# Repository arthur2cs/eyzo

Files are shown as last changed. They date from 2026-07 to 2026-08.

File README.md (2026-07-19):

# eyzo

Eyzo - contrôle des lunettes connectées ESP32

## Getting Started

This project is a starting point for a Flutter application.

A few resources to get you started if this is your first Flutter project:

- [Lab: Write your first Flutter app](https://docs.flutter.dev/get-started/codelab)
- [Cookbook: Useful Flutter samples](https://docs.flutter.dev/cookbook)

For help getting started with Flutter development, view the
[online documentation](https://docs.flutter.dev/), which offers tutorials,
samples, guidance on mobile development, and a full API reference.

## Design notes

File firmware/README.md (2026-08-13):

# Firmware ESP32 — Lunettes Eyzo

Firmware pour le **Seeed Studio XIAO ESP32S3**, pilotant les 2 écrans SPI
ST7735S 1,77" et le bouton poussoir des lunettes, et implémentant le
protocole BLE défini dans `specs.md` (§6) à la racine du projet.

Le code source est dans le dossier [`EyzoFirmware/`](./EyzoFirmware) — c'est
ce dossier qu'il faut ouvrir dans Arduino IDE (double-clic sur
`EyzoFirmware.ino`).

> Ce firmware a été **compilé avec succès** (`arduino-cli compile`, core
> `esp32:esp32` v3.3.11, carte `XIAO_ESP32S3`, PSRAM=OPI) — 17 % flash / 12 %
> RAM utilisés (dernière vérification). Le socle (écrans, bouton, connexion
> BLE, envoi de texte/images/animations compressés en zlib via
> `SET_ANIMATION`) **a été validé sur le matériel réel** — **important :
> nécessite l'option `PSRAM=OPI` activée dans Arduino IDE**
> (`Outils > PSRAM > OPI PSRAM`), sans quoi le buffer de réassemblage BLE ne
> s'alloue pas et toute commande échoue silencieusement (voir §5 sur
> l'ACK/NACK applicatif, désormais consommé côté app). Les nouvelles
> cadences de défilement/clignotement (`stepIntervalFromSpeed()` /
> `blinkHalfPeriodFromSpeed()`, voir §4) sont en revanche **encore
> seulement validées à la compilation**, pas encore testées sur le matériel
> réel.

## 1. Installation Arduino IDE

### 1.1 Support de carte ESP32

1. **Fichier > Préférences**, champ "URL de gestionnaire de cartes
   supplémentaires", ajouter (si "esp32" n'apparaît pas déjà nativement dans
   le gestionnaire de cartes) :
   ```
   https://raw.githubusercontent.com/espressif/arduino-esp32/gh-pages/package_esp32_index.json
   ```
2. **Outils > Type de carte > Gestionnaire de cartes**, rechercher `esp32`
   (par **Espressif Systems**), installer. Version testée : **3.3.11**.
3. **Outils > Type de carte > esp32 > XIAO_ESP32S3**.
4. **Outils > PSRAM > "OPI PSRAM"** — **important**, à activer : le firmware
   stocke les frames d'animation en PSRAM (le XIAO ESP32S3 embarque 8 Mo de
   PSRAM). Sans ce réglage, les animations multi-frames échoueront à
   s'allouer (repli automatique en RAM interne, mais avec une capacité bien
   plus faible).
5. Les autres réglages (Partition Scheme, Upload Speed, etc.) peuvent rester
   sur leurs valeurs par défaut.
6. Brancher le XIAO en USB-C, sélectionner le bon port dans **Outils > Port**.
   Le XIAO ESP32S3 a un circuit de reset automatique : l'upload ne devrait
   pas nécessiter de manipulation du bouton BOOT.

### 1.2 Librairies (Gestionnaire de bibliothèques : **Outils > Gérer les

bibliothèques…**)

| Librairie | Auteur | Version testée | Usage |
| --- | --- | --- | --- |
| `NimBLE-Arduino` | h2zero | 2.5.1 | Serveur BLE (bien plus léger en RAM que la lib Bluedroid intégrée) |
| `Adafruit GFX Library` | Adafruit | 1.12.6 | Primitives de dessin + framebuffer (`GFXcanvas16`) |
| `Adafruit ST7735 and ST7789 Library` | Adafruit | 1.11.0 | Driver des dalles ST7735S |
| `zlib_turbo` | Larry Bank (bitbank2) | 1.0.0 | Décompression zlib/deflate (RFC1950) des bitmaps texte/image compressés côté app, voir §4 |

`Adafruit BusIO` est installée automatiquement comme dépendance de la lib
Adafruit ST7735. `Preferences.h` et `SPI.h` sont fournies nativement par le
core ESP32, aucune installation nécessaire.

Recherchez chaque librairie par son nom exact ci-dessus dans le champ de
recherche du Gestionnaire de bibliothèques et installez la version indiquée
(ou plus récente — l'API NimBLE 2.x utilisée ici est stable depuis la 2.0).

### 1.3 Compiler / téléverser

**Croquis > Vérifier/Compiler**, puis **Croquis > Téléverser**. Ouvrir le
**Moniteur série** (115200 bauds) pour voir les logs (`Serial.println`) en
cas de problème (échec d'allocation mémoire, etc.).

## 2. Schéma de câblage

### 2.1 Répartition des signaux

Bus SPI **partagé** (SCK + MOSI) entre les 2 écrans — seuls le CS
(sélection de puce) et le RST (reset) sont **séparés par écran**. DC
(Data/Command) est partagé : sans effet indésirable, il n'est lu par chaque
contrôleur que pendant que son propre CS est actif.

> ⚠️ **Le RST ne doit pas être partagé entre les 2 écrans** : la lib
> Adafruit_ST7735 pulse la broche RST à chaque `initR()`, ce qui
> réinitialiserait aussi l'écran déjà configuré si le fil était commun. Voir
> le commentaire en tête de `display_manager.cpp`.

| Signal | Broche XIAO | GPIO | Écran / périphérique | Notes |
| --- | --- | --- | --- | --- |
| SPI**SCK** | D8 | GPIO7 | Gauche + Droit (partagé) | Horloge SPI |
| SPI**MOSI** | D10 | GPIO9 | Gauche + Droit (partagé) | Données SPI (écriture seule, pas de MISO) |
| **DC** (A0/RS) | D2 | GPIO3 | Gauche + Droit (partagé) | Data/Command |
| **CS** écran Gauche  | D0 | GPIO1 | Écran Gauche | Chip Select |
| **CS** écran Droit | D1 | GPIO2 | Écran Droit | Chip Select |
| **RST** écran Gauche | D3 | GPIO4 | Écran Gauche | Reset —**non partagé** |
| **RST** écran Droit  | D4 | GPIO5 | Écran Droit | Reset —**non partagé** |
| **Bouton poussoir** | D5 | GPIO6 | Bouton | `INPUT_PULLUP`, autre broche du bouton vers GND |
| 3V3 | — | — | Gauche + Droit (VCC), BLK si présent | Alimentation logique/panneau |
| GND | — | — | Gauche + Droit + Bouton | Masse commune |
| *libre / réservé* | D6, D7, D9  | GPIO43, GPIO44, GPIO8 | — | Ex. pont diviseur batterie (specs.md §6.4, non câblé ici) |

`D9`/GPIO8 (MISO par défaut du bus SPI matériel) n'est **pas utilisé** —
les écrans ne sont jamais lus, seulement écrits. Le firmware initialise le
bus SPI avec `SPI.begin(SCK, -1, MOSI, -1)` pour ne pas le réserver, il
reste donc disponible plus tard si besoin (ex. lecture batterie).

### 2.2 Schéma (vue de dessus, USB-C en haut)

Schéma de brochage et de câblage du XIAO ESP32S3 pour les lunettes Eyzo

*(fichier [`wiring-diagram.svg`](./wiring-diagram.svg) — s'ouvre aussi
directement dans un navigateur si l'aperçu ne s'affiche pas dans votre
visionneuse Markdown)*

Détail des connexions par écran (VCC/GND non répétés sur le schéma ci-dessus
par souci de lisibilité — communs aux 2 écrans) :

| | Écran GAUCHE | Écran DROIT |
| --- | --- | --- |
| VCC | 3V3 | 3V3 |
| GND | GND | GND |
| SCL / SCK | D8 (partagé) | D8 (partagé) |
| SDA / MOSI | D10 (partagé) | D10 (partagé) |
| DC / A0 | D2 (partagé) | D2 (partagé) |
| RES / RST | **D3 (dédié)** | **D4 (dédié)** |
| CS | **D0 (dédié)** | **D1 (dédié)** |
| BLK / LED (si présent) | 3V3 (rétroéclairage fixe) | 3V3 (rétroéclairage fixe) |

Vérifiez que vos modules d'écran acceptent bien une alimentation **3,3 V**
directe (c'est le cas de la quasi-totalité des breakouts ST7735 courants,
qui embarquent souvent déjà un régulateur/level-shifter, mais à vérifier sur
la référence exacte utilisée — le XIAO ESP32S3 est un MCU 3,3 V, ses GPIO ne
sont **pas** tolérants 5 V).

## 3. Comportement BLE ("comme une enceinte")

Voir `ble_manager.cpp`/`.h` pour le détail. Résumé du comportement implémenté
(specs.md §4.1) :

- **Aucun appareil mémorisé** (1er allumage, ou après un ré-appairage) : le
  firmware accepte et mémorise automatiquement (en NVS, via `Preferences`)
  le **premier téléphone qui se connecte** — pas besoin d'appui bouton pour
  cette toute première connexion.
- **Appareil déjà mémorisé** : le firmware advertise en continu tant qu'il
  n'est pas connecté ; l'app Flutter se reconnecte automatiquement par
  adresse au démarrage et après coupure (`autoReconnectProvider`). Aucune
  action nécessaire.
- **Appareil inconnu qui tente de se connecter** (adresse différente de
  celle mémorisée) : **rejeté immédiatement** (déconnexion forcée), sauf
  pendant la fenêtre d'appairage.
- **Appui long (≥ 800 ms) sur le bouton** : ouvre une fenêtre d'appairage de
  60 s (`PAIRING_WINDOW_MS`, réglable dans `config.h`). Pendant cette
  fenêtre, un nouvel appareil peut se connecter et devient le nouvel
  appareil mémorisé, **remplaçant** l'ancien (modèle "un seul propriétaire à
  la fois", comme le bouton pairing d'une enceinte Bluetooth classique). Si
  un téléphone était déjà connecté au moment de l'appui long, il est
  déconnecté pour laisser la place.
- Écran affiché pendant l'appairage : `Appairage 60s` (compte à rebours
  simplifié, pas de rafraîchissement seconde par seconde).

**Limite BLE assumée** : un appareil non reconnu reste visible dans un scan
(l'advertising BLE ne peut pas être filtré par identité sans un
appairage/liste blanche au niveau liaison, hors scope ici) — seule la
**connexion** est refusée hors fenêtre d'appairage. C'est le comportement
pratique qui compte pour l'usage "enceinte", mais à garder en tête.

## 4. Réception et affichage du contenu

- Le protocole (`protocol.h`) reproduit exactement
  `lib/core/ble/eyzo_protocol.dart` et `packet_builder.dart` côté app :
  mêmes UUID, même format de trame chunkée (SOF/CMD/SCREEN/SEQ/TOTAL/LEN/
  PAYLOAD/CHK), même checksum XOR.
- `ble_manager.cpp` réassemble les chunks reçus sur la caractéristique
  Commande, vérifie le checksum, puis transmet le payload complet à
  `display_manager.cpp` qui l'affiche (texte défilant/statique/clignotant,
  image statique, animation multi-frames, mode séquentiel 2 écrans en bande
  continue).
- **Compression** : les pixels RGB565 (texte comme image/animation) peuvent
  être envoyés compressés en zlib/deflate (RFC1950) — un octet `format` dans
  chaque payload (voir `protocol.h`) indique si les données qui suivent sont
  brutes ou compressées. Côté app, `packet_builder.dart` compresse avec
  `package:archive` (`ZLibEncoder`) et ne l'utilise que si ça réduit
  effectivement la taille transmise (repli sur le brut sinon, ex. contenu
  déjà très texturé/bruité qui compresse mal). Côté firmware,
  `ble_manager.cpp` décompresse avec `zlib_turbo` (voir tableau des libs
  ci-dessus) dans `resolvePixels()`/`decompressPixels()`, avant de transmettre
  les pixels à `display_manager.cpp` — ce dernier ne voit jamais de données
  compressées. Le gain est surtout net sur les bitmaps de texte (fond
  uni + quelques glyphes, très compressibles) et reste généralement positif
  sur les images/GIFs importés (résolution de travail réduite, palettes
  limitées), sans jamais dégrader la taille transmise dans le pire cas.
- **`SET_ANIMATION`** : toute l'animation est envoyée en **une seule
  commande** (une seule frame, chunkée, avant : autant de commandes que de
  frames) — les frames sont concaténées puis compressées **ensemble** côté
  app avant l'envoi, plutôt qu'indépendamment frame par frame. Ça laisse
  zlib référencer les frames voisines dans sa fenêtre de compression, très
  efficace pour un GIF/sticker typique (fond fixe, petite partie qui bouge),
  et ça réduit d'autant le nombre d'allers-retours BLE (un seul accusé
  applicatif pour toute l'animation). Côté firmware, `DisplayManager` stocke
  toutes les frames décompressées dans un unique buffer PSRAM contigu
  (`AnimationPlayer::combinedFrames`, voir `display_manager.cpp`) plutôt que
  N buffers séparés — la mise à jour de ce player est atomique (reset puis
  réaffectation en un bloc), donc l'animation précédemment affichée continue
  de tourner normalement pendant toute la réception de la nouvelle, sans
  geler ni passer par un écran noir intermédiaire.
- **Réglages** (police/taille/couleurs/direction) : rendus **côté app** en
  bitmap RGB565 fidèle à l'aperçu (voir `text_bitmap_renderer.dart` et
  specs.md §6.3) — le firmware ne fait plus de rendu de police, il
  affiche/défile ce bitmap tel quel (`blitBitmapWindow()` dans
  `display_manager.cpp`). `speed -> délai de défilement/clignotement` reste
  un mapping firmware (`stepIntervalFromSpeed()`/`blinkHalfPeriodFromSpeed()`
  dans `display_manager.cpp`), non spécifié précisément par le protocole
  (specs.md) — **mais désormais reproduit à l'identique côté app**
  (`lib/core/utils/glasses_timing.dart`) pour que l'aperçu affiche le même
  rythme que les lunettes : toute modification de ces deux fonctions doit
  être répercutée dans `glasses_timing.dart`, et inversement.

## 5. Points ouverts / limitations connues

- **Format de la caractéristique Événement** (ESP32 -> téléphone) : `EVT_ACK`/
  `EVT_NACK` sont désormais consommés côté app (voir `_onEvent` dans
  `eyzo_ble_service.dart`) — chaque commande envoyée attend l'accusé
  applicatif du firmware (avec timeout, voir `EyzoProtocol.ackTimeout`) avant
  d'être considérée comme réussie, plutôt que de se fier au seul succès de
  l'écriture BLE bas niveau. `EVT_STATUS`/`EVT_PAIRING` restent eux non
  exploités côté app pour l'instant (statut batterie/écrans, notification
  d'entrée/sortie du mode appairage) — à brancher si besoin.
- **Batterie** (specs.md §6.4) : non implémentée — nécessite un pont
  diviseur de tension câblé sur une broche ADC libre (D6/D7/D9 disponibles),
  non présent dans ce schéma. `GET_STATUS` répond toujours "écrans OK" sans
  sonde matérielle réelle.
- **Orientation/variante des écrans** : `setRotation(1)` et
  `INITR_BLACKTAB` sont les valeurs les plus courantes pour ce type de
  dalle, mais varient selon le fournisseur — si l'image sort tournée,
  inversée ou avec des couleurs décalées, essayer `setRotation(3)` et/ou
  `INITR_GREENTAB`/`INITR_REDTAB` dans `display_manager.cpp` (`begin()`).
- **Un seul appareil connecté à la fois** : pas de multipoint (2 téléphones
  connectés simultanément) — cohérent avec le modèle "enceinte" demandé,
  mais à signaler si un usage multi-téléphone est souhaité un jour.

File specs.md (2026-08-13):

# Eyzo — Spécifications

Application Flutter (Android) permettant d'envoyer du texte défilant et des animations à des lunettes connectées custom, équipées d'un ESP32 et de 2 écrans LCD indépendants.

Ce document sert de contrat de référence pour le développement de l'app **et** du firmware ESP32 (protocole de communication).

---

## 1. Vue d'ensemble

- **Nom de l'application** : Eyzo
- **Icône** : panda mignon (fournie par l'utilisateur)
- **Plateforme cible** : Android (Flutter), version minimale API 26 (Android 8.0)
- **Objectif** : composer et envoyer, depuis le téléphone, du texte défilant, des animations ou des images vers les 2 écrans des lunettes, indépendamment l'un de l'autre.

## 2. Matériel cible

- **MCU** : Seeed Studio XIAO ESP32S3 (240 MHz, WiFi + BLE, Arduino/MicroPython)
- **Écrans** : 2x écran TFT SPI 1,77" ST7735S, résolution 128x160 (dalle native), montés en orientation **paysage** dans les lunettes → résolution effective 160x128, couleur (RGB565)
- **Écran gauche / écran droit** : pilotés indépendamment, chacun peut afficher un contenu différent
- **Firmware ESP32** : pas encore développé — ce document définit le protocole de communication qu'il devra implémenter

## 3. Design / UI

- **Thème** : dark mode uniquement (pas de light mode), noir dominant / texte blanc
- **Style** : minimaliste et sobre dans la structure, mais avec une touche kawaii assumée en clin d'œil à l'icône panda — typographie et boutons généreux/arrondis plutôt que stricts
- **Icône app** : panda mignon (asset fourni par l'utilisateur, à intégrer dans `assets/icon/`)
- **Palette inspirée du panda** :
  - Noir/blanc en base
  - Gris `#59595C` (tache "à lunettes" du panda) pour les bordures et éléments neutres
  - Rose `#FB7B77` (langue du panda) en accent vif, réservé à **exactement 3 usages** : le statut "connecté", l'indicateur de navigation (Accueil/Favoris/Paramètres) et le focus des champs de texte (bordure pendant la saisie, icône favoris une fois enregistré) — jamais dans les sélections/contrôles des pages (chips, segmented button, slider restent en blanc/noir neutre)
- **Typographie** : police arrondie et généreuse (Quicksand) pour un rendu plus doux/amical que la police système par défaut ; boutons avec padding et rayons de bordure généreux (20dp). Police embarquée localement dans `assets/fonts/` (aucun téléchargement au premier lancement)
- **Aperçu miroir** : les écrans de composition affichent les 2 verres côte à côte selon la convention "je vois ce que le porteur montre au public" — le verre **droit** du porteur est affiché à **gauche** dans l'app, le verre **gauche** du porteur à **droite** (vue miroir, comme se faire face)
- **Format des cadres d'aperçu** : dessinés au ratio **3:2** (plus large que haut) pour un rendu visuellement plus proche d'un vrai petit écran de lunettes que le ratio natif 5:4 du panneau ST7735S en orientation paysage (160x128) — un choix esthétique côté app, sans lien avec la résolution réelle des données envoyées (voir §6.3)

## 4. Fonctionnalités

### 4.1 Connexion aux lunettes (BLE)

- Protocole : **Bluetooth Low Energy (BLE)**
- Scan BLE avec liste des appareils détectés, appairage à un appareil "Eyzo Glasses"
- Mémorisation de l'appareil appairé (device id) + **reconnexion automatique** au lancement de l'app et en cas de coupure
- Écran/possibilité de "oublier l'appareil" pour ré-appairer
- **Indicateur de statut de connexion** visible en permanence (ex: bandeau ou icône dans l'AppBar) : connecté / déconnecté / en cours de connexion
- **Niveau de batterie des lunettes** affiché si disponible (voir §6.4 — dépend de la capacité matérielle du XIAO ESP32S3 à lire la tension batterie ; à valider côté firmware/hardware, non garanti par défaut)
- Permissions Android gérées au runtime :
  - Android 12+ (API 31+) : `BLUETOOTH_SCAN`, `BLUETOOTH_CONNECT`
  - Android 8–11 (API 26–30) : `BLUETOOTH`, `BLUETOOTH_ADMIN`, `ACCESS_FINE_LOCATION` (requis par le système pour le scan BLE)

### 4.2 Texte défilant

- Champ de saisie de texte, mode **"écrire puis envoyer"** (pas de live typing)
- Sélection de l'écran cible : **Gauche / Droit / Simultané / Séquentiel**
  - Gauche, Droit, Simultané : contenu identique ou indépendant sur chaque écran (comme pour les autres modes de contenu, voir §6.2)
  - **Séquentiel (texte uniquement)** : les 2 écrans forment une seule bande de défilement continue — le texte part d'un écran et continue sur l'autre. L'écran de départ dépend de la direction : en défilement "←" le texte entre par l'écran Gauche et sort par l'écran Droit ; en "→" c'est l'inverse (voir §6.3 pour le détail protocole). Sans effet particulier en mode statique/clignotant (équivalent à Simultané dans ce cas).
- Réglages disponibles :
  - **Vitesse** (slider, niveau 1–10) : pas de défilement en mode défilement, cadence de clignotement en mode clignotant (deux mappings distincts, voir §6.3 — sans effet en mode statique)
  - **Couleur du texte et couleur de fond** (color picker, rendu RGB565 sur les écrans)
  - **Police et taille de caractère** (liste de polices bitmap embarquées côté firmware, sélection par id)
  - **Direction / mode** : défilement gauche→droite, droite→gauche, statique, clignotant
- **Aperçu double-verre** dans l'app avant envoi, y compris pour le mode Séquentiel (simulateur des 2 écrans 160x128 miniatures, voir §3)
- Bouton "Envoyer" + bouton "Ajouter aux favoris"

### 4.3 Import d'image / GIF

- Import depuis la galerie du téléphone (image fixe ou GIF animé, y compris les GIF enregistrés depuis un clavier/une autre app dans la galerie)
- **Insertion directe depuis la banque de GIF du clavier** (Gboard, etc.) : un champ dédié reçoit le GIF choisi dans le clavier via le mécanisme Android `commitContent`, exposé côté Flutter par `contentInsertionConfiguration` sur `TextField`
  - Le clavier transmet soit les octets du GIF directement, soit une URI `content://` — dans ce second cas (le plus fréquent pour des GIF, plus volumineux), l'app lit l'URI via un petit pont natif Android (`MethodChannel` + `ContentResolver.openInputStream`, voir `MainActivity.kt`)
  - Ne nécessite ni compte, ni clé API, ni connexion Internet côté app (le clavier gère lui-même le téléchargement/cache du GIF)
  - ~~Recherche Tenor intégrée~~ abandonnée : Tenor n'accepte plus de nouveaux clients API depuis janvier 2026
- Redimensionnement/conversion automatique vers la résolution de travail (voir §4.4) avant transfert — jamais de déformation ; deux modes de cadrage au choix (**Remplir**, par défaut, ou **Image entière**), voir ci-dessous
- **Mode de cadrage** :
  - **Remplir** *(par défaut)* : la plus petite dimension colle aux bords de la grille, le surplus sur l'autre dimension est recadré (crop centré)
  - **Image entière** : l'image est incluse en entier, quitte à laisser des bandes noires (letterbox/pillarbox) sur les bords
- Aperçu double-verre avant envoi
- Sélection de l'écran cible

### 4.4 Éditeur pixel-art

- Grille de dessin en **basse résolution** (ex: 40x32 ou 80x64, configurable) — l'app fait l'**upscale** (nearest-neighbor) pour remplir l'écran 160x128 réel, à la fois pour l'aperçu app et pour le rendu final sur les lunettes
- Outils : pixel, ligne, remplissage (bucket), gomme, palette de couleurs
- Gestion multi-frames : ajouter / dupliquer / supprimer une frame, réglage du délai entre frames (animation image par image)
- Aperçu animé en direct dans l'app
- Sauvegarde en favoris, envoi vers écran gauche / droit / simultané

### 4.5 Favoris & historique

- Bibliothèque locale de contenus sauvegardés (textes, animations importées/dessinées, images)
- Réutilisation en un tap (renvoyer, dupliquer, éditer, supprimer)
- Stockage **local uniquement** sur le téléphone (pas de compte, pas de cloud) — base de données locale embarquée (ex: Hive)

### 4.6 Paramètres

- Gestion de l'appareil appairé (info, oublier, reconnecter)
- À propos / version de l'app

## 5. Architecture applicative (écrans Flutter)

1. **Accueil / Dashboard** — statut de connexion, batterie, accès rapide aux 3 modes de contenu
2. **Connexion** — scan BLE, appairage, gestion de l'appareil
3. **Texte** — composition + réglages + aperçu double-verre + envoi
4. **Import** — sélection galerie/GIF + aperçu/recadrage + envoi
5. **Éditeur pixel-art** — canvas, outils, gestion de frames, aperçu, envoi
6. **Favoris / Historique** — liste, actions rapides
7. **Paramètres**

## 6. Protocole de communication BLE (contrat App ↔ Firmware)

> Ce protocole est une **proposition** à valider/affiner avec le développement du firmware ESP32. Les UUID ci-dessous sont des exemples à figer définitivement en phase d'implémentation.

### 6.1 Services & caractéristiques GATT

| Élément | UUID (exemple) | Type | Description |
|---|---|---|---|
| Service Eyzo | `4e4a0001-6f61-4c1e-8c3a-4e4a656f7a30` | Service | Service principal de contrôle |
| Caractéristique Commande | `4e4a0002-6f61-4c1e-8c3a-4e4a656f7a30` | Write / Write No Response | Phone → ESP32, envoi des trames de commande (chunkées) |
| Caractéristique Événement | `4e4a0003-6f61-4c1e-8c3a-4e4a656f7a30` | Notify | ESP32 → Phone, ACK/NACK, erreurs, statut |
| Service Batterie | `0x180F` (standard BLE) | Service | Battery Service standard, si lecture batterie possible |
| Battery Level | `0x2A19` (standard BLE) | Read / Notify | Niveau de batterie en % |

- Négociation MTU côté app : demander un MTU élevé (jusqu'à 247–517 octets) pour limiter le nombre de paquets lors des transferts d'image/animation.

### 6.2 Format de trame (caractéristique Commande)

En-tête commun à chaque paquet (chunk) :

| Octets | Champ | Description |
|---|---|---|
| 1 | `SOF` | Marqueur de début, `0xAA` |
| 1 | `CMD` | Identifiant de commande (voir §6.3) |
| 1 | `SCREEN` | Écran cible : `0x00` gauche, `0x01` droit, `0x02` simultané, `0x03` séquentiel (texte uniquement, voir §6.3) |
| 2 | `SEQ` | Index du chunk courant (uint16 LE) |
| 2 | `TOTAL` | Nombre total de chunks pour ce contenu (uint16 LE) |
| 2 | `LEN` | Longueur du payload dans ce chunk (uint16 LE) |
| N | `PAYLOAD` | Données (voir formats par commande) |
| 1 | `CHK` | Checksum (XOR ou CRC8 des octets précédents) |

### 6.3 Commandes

| CMD | Nom | Description |
|---|---|---|
| `0x01` | `SET_TEXT` | Envoi d'un texte défilant, sous forme de bitmap déjà rendu côté app (chunké) |
| `0x02` | `SET_STATIC_IMAGE` | Envoi d'une image statique (chunké) |
| `0x03` | `SET_ANIMATION` | Envoi de l'animation complète — toutes les frames en une seule commande (chunké) |
| `0x04` | `CLEAR_SCREEN` | Efface l'écran cible |
| `0x05` | `PING` | Keep-alive |
| `0x06` | `GET_STATUS` | Demande de statut (batterie, connexion écrans) |

#### Payload `SET_TEXT`

Le texte est rendu **côté app** en bitmap RGB565, avec la police/taille/couleur
exactement telles que dans l'aperçu de composition (voir
`text_bitmap_renderer.dart`) : le firmware ne rend plus aucune police
lui-même, il se contente d'afficher/défiler ce bitmap tel quel. Ceci élimine
l'écart entre l'aperçu app et le rendu réel sur les lunettes (police interne
ESP32 différente, mapping de taille grossier).

| Octets | Champ |
|---|---|
| 1 | `direction` (0=gauche, 1=droite, 2=statique, 3=clignotant) |
| 1 | `speed` (niveau 1–10) |
| 2 | `color_bg` (RGB565 LE) |
| 2 | `width` (uint16 LE) |
| 1 | `height` (toujours égal à la hauteur native de l'écran, 128) |
| 2 | `gap_native_px` (uint16 LE) — écart inter-écran en pixels natifs, uniquement significatif pour `SCREEN = 0x03` (séquentiel), ignoré sinon |
| 1 | `format` (0=brut, 1=compressé zlib — voir "Compression" ci-dessous) |
| N | pixels RGB565 big-endian, row-major (`width * height * 2` octets si `format=0` ; sinon flux zlib de ces mêmes octets) |

- `direction` statique/clignotant : bitmap **plein écran** (`width` = 160,
  `height` = 128), fond déjà peint dedans — le firmware l'affiche/le masque
  tel quel (clignotement) sans autre calcul. `speed` pilote la cadence de
  clignotement (`blinkHalfPeriodFromSpeed()` dans display_manager.cpp) — un
  mapping différent de celui du défilement (`stepIntervalFromSpeed()`),
  reproduit à l'identique côté app dans `glasses_timing.dart` pour que
  l'aperçu et l'affichage réel restent synchronisés. Sans effet en mode
  statique.
- `direction` défilement : bitmap resserré sur le texte seul (`width` =
  largeur réelle du texte rendu, `height` = 128) — le firmware repeint le
  fond avec `color_bg` à chaque pas et y positionne une fenêtre glissante du
  bitmap (translation pure, pas de nouveau rendu de police), exactement comme
  il le faisait déjà pour le défilement du texte natif.
- Un bitmap de texte peut peser nettement plus qu'une image plein écran pour
  un message long à grande taille de police (limite : voir `maxPayloadSize`
  côté app / `MAX_PAYLOAD_SIZE` côté firmware, ~1,5 Mo — dimensionnée pour
  couvrir le plus gros cas d'usage réel, une animation complète envoyée en
  un seul bloc via `SET_ANIMATION`, mesurée **avant** compression) — l'app
  rejette l'envoi avant transmission si ce plafond est dépassé plutôt que de
  laisser un transfert BLE de plusieurs minutes.

**Mode séquentiel (`SCREEN = 0x03`, `SET_TEXT` uniquement)** : les 2 écrans sont traités par le firmware comme une seule bande de défilement continue (largeur virtuelle = 2x la largeur d'un écran + `gap_native_px`), au lieu de dupliquer le même texte sur chaque écran indépendamment. L'écran de départ dépend du champ `direction` de ce même payload :
- `direction = 0` (défilement ←) : le texte entre par l'écran **Gauche** et sort par l'écran **Droit**.
- `direction = 1` (défilement →) : le texte entre par l'écran **Droit** et sort par l'écran **Gauche**.
- `direction = 2` (statique) ou `3` (clignotant) : pas de déplacement possible entre écrans — le firmware doit traiter `SCREEN = 0x03` comme équivalent à `0x02` (simultané) dans ce cas.
- `gap_native_px` élargit la bande virtuelle de cet écart : le texte est invisible le temps de le traverser (à la même vitesse en pixels natifs/seconde que le défilement), exactement comme dans l'aperçu (`SequentialTextPreview`/`_nativeGapPx`) — les 2 restent ainsi synchronisés, l'écart réglé par l'utilisateur (`interLensGapProvider`) n'étant plus une simulation purement visuelle côté app.

`SCREEN = 0x03` n'est pas utilisé par `SET_STATIC_IMAGE` / `SET_ANIMATION` (non exposé côté app pour ces commandes) ; comportement non défini si reçu par le firmware pour ces commandes.

#### Payload `SET_STATIC_IMAGE`

| Octets | Champ |
|---|---|
| 1 | `width` (résolution de travail, ex: ≤ 64) |
| 1 | `height` |
| 1 | `format` (0=brut, 1=compressé zlib — voir "Compression" ci-dessous) |
| 2 | `data_len` (longueur de `data` **telle que transmise**, donc après compression si `format=1`) |
| N | `data` : pixels RGB565 (row-major) si `format=0` ; sinon flux zlib de ces mêmes octets — répartis sur plusieurs chunks selon `SEQ`/`TOTAL` |

#### Payload `SET_ANIMATION`

Toute l'animation part en **une seule commande** (plus un envoi par frame
comme avant) : les frames sont concaténées puis compressées **ensemble**
avant l'envoi, voir "Compression" ci-dessous.

| Octets | Champ |
|---|---|
| 1 | `width` (résolution de travail, ex: ≤ 64) |
| 1 | `height` |
| 1 | `frame_count` |
| 2 | `frame_delay_ms` (uniforme pour toute l'animation) |
| 1 | `format` (0=brut, 1=compressé zlib — voir "Compression" ci-dessous) |
| N | `data` : `frame_count` frames RGB565 (row-major) concaténées dans l'ordre si `format=0` ; sinon flux zlib de ces mêmes octets — répartis sur plusieurs chunks selon `SEQ`/`TOTAL` |

#### Compression (`format`, `SET_TEXT`/`SET_STATIC_IMAGE`/`SET_ANIMATION`)

Les pixels RGB565 peuvent être envoyés compressés en **zlib/deflate
(RFC1950)** plutôt que bruts, pour réduire le nombre de chunks BLE à
transmettre (le débit BLE, pas le rendu, domine le temps d'envoi pour un
message un peu long — voir §9). Le champ `format` (0=brut, 1=zlib) précède
les pixels dans chaque payload concerné ; la taille décompressée attendue
n'est jamais retransmise séparément, elle se déduit toujours des champs déjà
présents dans le même payload (`width * height * 2`, ou `width * height * 2
* frame_count` pour `SET_ANIMATION`).

- **App** (`packet_builder.dart`) : compression avec `package:archive`
  (`ZLibEncoder`) ; n'est utilisée que si elle réduit effectivement la taille
  transmise, sinon repli sur `format=0` (brut) — jamais de régression de
  taille pour un contenu peu compressible (ex. image très texturée/bruitée).
- **Firmware** (`ble_manager.cpp`) : décompression avec la lib `zlib_turbo`
  (voir `firmware/README.md`) avant transmission à `display_manager.cpp`, qui
  ne voit donc jamais de données compressées. Rejet (`NACK`, `ERR_DECOMPRESS`)
  si la décompression échoue ou ne produit pas exactement la taille attendue.
- Le gain est le plus net sur les bitmaps de texte (fond uni + quelques
  glyphes) mais reste généralement positif sur les images/GIFs importés
  (résolution de travail réduite, palettes limitées, voir §4.5).
- **`SET_ANIMATION` spécifiquement** : compresser toutes les frames en un
  seul flux (plutôt qu'indépendamment frame par frame comme avant) laisse
  zlib référencer les frames voisines dans sa fenêtre de compression — très
  efficace quand des frames consécutives se ressemblent (fond fixe, petite
  partie qui bouge, cas fréquent pour un GIF/sticker importé), ce qu'une
  compression par frame ne peut jamais exploiter. Une seule commande BLE
  pour toute l'animation réduit aussi d'autant le nombre d'allers-retours
  BLE (un accusé applicatif au lieu d'un par frame, voir §6.2).

> Le firmware reçoit l'image en basse résolution (grille de l'éditeur) et effectue l'**upscale nearest-neighbor** vers les 160x128 réels de l'écran ST7735S (orientation paysage), afin de limiter le volume de données transmis en BLE (une image plein format 160x128 en RGB565 pèse ~40 Ko, ce qui reste lourd pour une transmission fluide en BLE, surtout pour des animations multi-frames).

### 6.4 Batterie

- Le XIAO ESP32S3 n'a pas de fuel-gauge dédié, mais dispose d'un connecteur batterie LiPo + circuit de charge intégré. La lecture du niveau de batterie nécessite un pont diviseur de tension vers une broche ADC, câblé et calibré côté hardware/firmware.
- **À valider en phase de développement firmware** : si réalisable, exposer la valeur via le service Battery standard (`0x180F` / `0x2A19`). Sinon, l'app masque simplement l'indicateur de batterie et n'affiche que le statut de connexion.

## 7. Stack technique proposée (Flutter)

- **BLE** : `flutter_blue_plus` (scan, connexion, gestion MTU, write/notify)
- **State management** : Riverpod (proposition — à valider, ouvert à discussion)
- **Stockage local** : Hive (favoris, historique, animations custom)
- **Traitement image** : package `image` (redimensionnement, conversion RGB565), `image_picker` (import galerie/GIF)
- **Banque de GIF externe** : insertion clavier via `contentInsertionConfiguration` (Flutter) + pont natif Android (`MethodChannel` Kotlin) pour la lecture des URI `content://`
- **Icône d'app** : `flutter_launcher_icons` avec l'asset panda fourni
- **Typographie** : police Quicksand embarquée localement (`assets/fonts/`, licence SIL OFL), déclarée nativement via `pubspec.yaml` — pas de dépendance réseau

## 8. Roadmap proposée

**Phase 1 — MVP**
- Connexion BLE (scan, appairage, reconnexion auto, statut de connexion)
- Texte défilant (réglages complets) + envoi
- Favoris (texte)

**Phase 2**
- Import image/GIF (galerie + banque externe)

**Phase 3**
- Éditeur pixel-art (multi-frames)

**Phase 4**
- Batterie (si faisable matériellement)
- Polish UI, historique complet

## 9. Points ouverts / risques

- **UUID GATT** : valeurs d'exemple à figer définitivement avec le développement du firmware.
- **Débit BLE** : à mesurer en conditions réelles pour calibrer la résolution max de travail de l'éditeur/import (40x32, 80x64, ou plus) sans dégrader l'expérience (temps d'envoi trop long).
- **Lecture batterie** : dépend d'un ajout matériel (pont diviseur) sur le XIAO ESP32S3, non garanti par défaut.
- **Rendu texte sur écran** : le texte est rendu en bitmap côté app (voir §6.3) plutôt que par des polices embarquées firmware — fidèle à l'aperçu par construction, au prix d'un payload BLE plus lourd pour les messages longs/grande taille de police en mode défilement (plafonné, voir `maxPayloadSize`).
- **Deux écrans SPI simultanés** : sujet firmware/hardware (bus SPI partagé ou non), sans impact direct sur l'app tant que le contrat `SCREEN` (gauche/droit/simultané/séquentiel) est respecté.
- **Mode séquentiel** : la convention départ/arrivée selon la direction (voir §6.3) est un choix documenté côté app, à valider/ajuster une fois le rendu réel testé sur le firmware — c'est le firmware qui implémente concrètement le rendu "bande continue" à travers les 2 écrans.
- **Insertion GIF clavier** : dépend du clavier utilisé (Gboard le supporte via `commitContent` ; certains claviers tiers peuvent ne pas l'implémenter, auquel cas seul l'import galerie reste disponible). Comportement à valider sur plusieurs claviers/appareils réels.
- **Refus ponctuel côté clavier** : le clavier peut, pour un GIF donné, décider lui-même (toast natif, hors contrôle de l'app) que l'insertion n'est pas supportée ici — la liste de types MIME acceptés a été élargie (`image/*` en plus des types explicites) pour limiter ces cas, mais un rejet natif du clavier ne peut pas toujours être intercepté côté app ; la galerie reste le filet de sécurité.
- **Résolution plein écran (160x128) en import** : disponible en option, mais une animation multi-frames à cette résolution peut représenter plusieurs centaines de Ko à transférer en BLE — à utiliser avec parcimonie tant que le débit réel n'est pas mesuré (voir point ci-dessus sur le débit BLE).

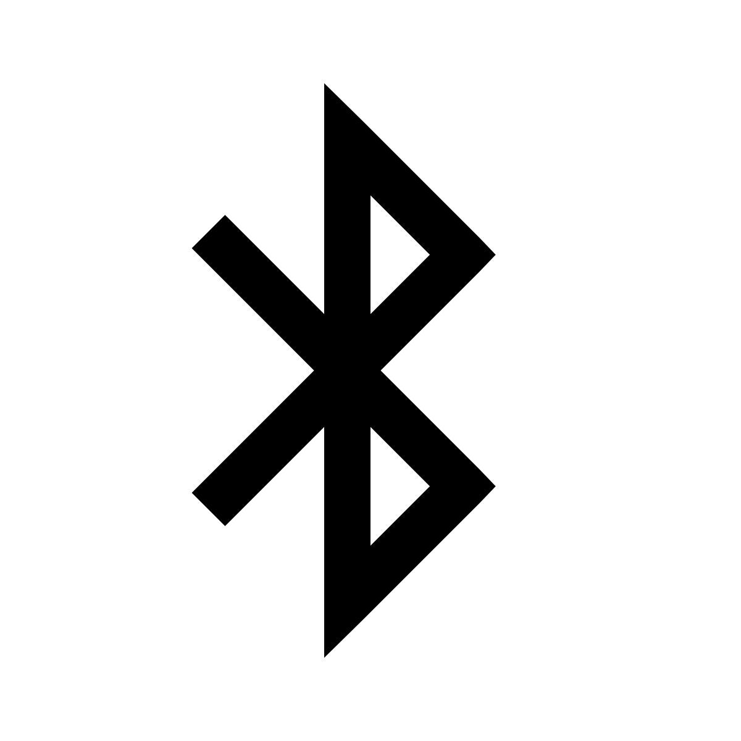
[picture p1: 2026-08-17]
bluetooth.jpg

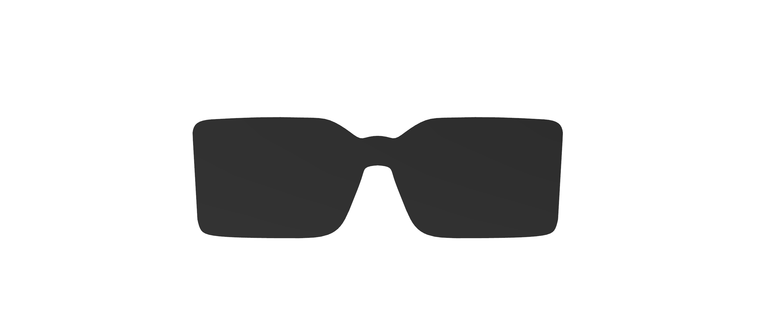
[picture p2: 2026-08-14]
firmware/EyzoFirmware/Eyzo.png

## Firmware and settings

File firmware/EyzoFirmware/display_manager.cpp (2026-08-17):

#include "display_manager.h"

#include <Adafruit_GFX.h>
#include <Adafruit_ST7735.h>
#include <SPI.h>
#include <esp_heap_caps.h>
#include <math.h>

#include "bluetooth_icon.h"
#include "config.h"
#include "panda_boot_icon.h"
#include "protocol.h"

// Notes d'implémentation importantes (voir specs.md §6.3 et les modèles Dart
// correspondants) :
//
// - Les champs scalaires de l'en-tête/payload (SEQ, TOTAL, LEN, color_fg,
//   color_bg, text_len, pixel_len, frame_delay_ms) sont encodés en
//   little-endian par l'app (voir `_uint16le()` dans packet_builder.dart).
//   Le décodage LE est fait par ble_manager.cpp AVANT d'appeler ce module.
//
// - Le TABLEAU DE PIXELS `pixelsRgb565` est en revanche encodé en BIG-endian
//   par pixel (voir `PixelFrame.getPixel/setPixel` dans pixel_animation.dart :
//   `pixelsRgb565[i] << 8 | pixelsRgb565[i+1]`). C'est ce module qui décode
//   les pixels, dans upscaleNearestToCanvas() ci-dessous — ne pas confondre
//   les deux endianness.

namespace DisplayManager {
namespace {

// --- Écrans physiques (bus SPI partagé, CS/RST séparés, voir config.h) ---
Adafruit_ST7735 tftLeft(PIN_TFT_CS_LEFT, PIN_TFT_DC, PIN_TFT_RST_LEFT);
Adafruit_ST7735 tftRight(PIN_TFT_CS_RIGHT, PIN_TFT_DC, PIN_TFT_RST_RIGHT);

// Framebuffers en mémoire : on dessine dans le canvas puis on blitte d'un
// coup sur l'écran (évite le scintillement d'un dessin direct incrémental).
GFXcanvas16 canvasLeft(SCREEN_W, SCREEN_H);
GFXcanvas16 canvasRight(SCREEN_W, SCREEN_H);

enum class Mode : uint8_t { None, Text, StaticImage, Animation };

// Animation reçue et décodée en une seule commande (SET_ANIMATION, voir
// protocol.h) : toutes les frames arrivent concaténées dans un seul payload
// (mieux compressible côté app — zlib peut référencer les frames voisines,
// souvent très similaires d'une frame à l'autre, voir packet_builder.dart),
// stockées ici dans un unique buffer PSRAM contigu plutôt que N buffers
// séparés. Comme la mise à jour de ce player est désormais atomique (voir
// applyAnimationToChannel : reset() puis réaffectation de tous les champs
// se font en une seule fois, jamais visibles à moitié faits par la tâche
// loop() qui ne fait que lire), l'ancienne animation continue de tourner
// normalement pendant toute la durée de réception de la nouvelle — plus
// besoin d'écran noir/gel intermédiaire.
struct AnimationPlayer {
  uint8_t *combinedFrames = nullptr;  // frames concaténées, RGB565 big-endian
  uint8_t frameWidth = 0, frameHeight = 0;
  uint8_t frameCount = 0;
  uint8_t currentFrame = 0;
  uint16_t frameDelayMs = 120;
  uint32_t lastFrameMs = 0;

  // Vrai une fois combinedFrames entièrement rempli et prêt à être joué —
  // seul champ lu par updateAnimationChannel (tâche loop(), cœur 1) pendant
  // qu'applyAnimationToChannel (tâche BLE, cœur 0) répare ce player ; mis à
  // `false` en tout premier par reset() et à `true` en tout dernier, pour
  // qu'il ne soit jamais observé dans un état à moitié reconstruit.
  volatile bool ready = false;

  const uint8_t *frameAt(uint8_t index) const {
    if (!combinedFrames) return nullptr;
    const uint32_t frameBytes = (uint32_t)frameWidth * frameHeight * 2;
    return combinedFrames + (uint32_t)index * frameBytes;
  }

  void reset() {
    ready = false;
    if (combinedFrames) {
      heap_caps_free(combinedFrames);
      combinedFrames = nullptr;
    }
    frameWidth = 0;
    frameHeight = 0;
    frameCount = 0;
    currentFrame = 0;
    lastFrameMs = 0;
  }
};

struct ScreenChannel {
  Mode mode = Mode::None;

  // --- texte défilant/statique/clignotant : bitmap RGB565 déjà rendu côté
  // app (voir protocol.h), le firmware ne fait plus de rendu de police ---
  uint8_t *textBitmap = nullptr;  // big-endian/pixel, largeur textBitmapWidth x SCREEN_H
  uint16_t textBitmapWidth = 0;
  uint16_t colorBg = 0x0000;
  uint8_t direction = EyzoProtocol::DIR_STATIC;
  uint32_t stepIntervalMs = 60;
  int32_t scrollX = 0;
  uint32_t lastTickMs = 0;
  bool blinkOn = true;
  uint32_t lastBlinkMs = 0;
  uint32_t blinkHalfPeriodMs = 500;
  bool needsRedraw = true;

  // --- image statique ---
  uint8_t imgWidth = 0, imgHeight = 0;
  uint8_t *staticPixels = nullptr;  // copie du payload (RGB565 big-endian/pixel)

  // --- animation ---
  AnimationPlayer anim;

  void freeStatic() {
    if (staticPixels) {
      free(staticPixels);
      staticPixels = nullptr;
    }
  }

  void freeTextBitmap() {
    if (textBitmap) {
      heap_caps_free(textBitmap);
      textBitmap = nullptr;
    }
  }
};

ScreenChannel s_left;
ScreenChannel s_right;

// Mode séquentiel (SET_TEXT, SCREEN_SEQUENTIAL uniquement) : les 2 écrans
// forment une bande virtuelle continue de largeur 2*SCREEN_W (voir
// specs.md §6.3). État dédié, exclusif des channels ci-dessus tant qu'actif.
struct SequentialState {
  bool active = false;
  uint8_t *textBitmap = nullptr;
  uint16_t textBitmapWidth = 0;
  uint16_t colorBg = 0x0000;
  uint8_t direction = EyzoProtocol::DIR_LEFTWARD;
  uint32_t stepIntervalMs = 60;
  int32_t virtualX = 0;
  uint32_t lastTickMs = 0;
  bool needsRedraw = true;

  // Écart physique entre les 2 écrans, en pixels natifs (voir protocol.h) :
  // élargit la bande virtuelle (2*SCREEN_W + gapNativePx au lieu de
  // 2*SCREEN_W) — le texte y est invisible le temps de la traverser, comme
  // dans l'aperçu (sequential_text_preview.dart::_nativeGapPx).
  int32_t gapNativePx = 0;

  void freeTextBitmap() {
    if (textBitmap) {
      heap_caps_free(textBitmap);
      textBitmap = nullptr;
    }
  }
};

SequentialState s_seq;

// Écran d'état actif indépendant des channels ci-dessus (voir showBoot/
// showConnected/showDisconnected/showPairing) : seul l'appairage a besoin
// d'être réanimé en continu (barre de compte à rebours + logo qui "respire"),
// les 3 autres sont des images statiques dessinées une fois puis laissées
// telles quelles jusqu'au prochain appel.
enum class StatusScreen : uint8_t { None, Pairing };
StatusScreen s_statusScreen = StatusScreen::None;
uint32_t s_pairingStartMs = 0;
uint32_t s_pairingDurationMs = 0;
uint32_t s_lastPairingFrameMs = 0;

// --- DEBUG TEMPORAIRE : mesure de la cadence réelle de défilement, à
// retirer une fois le diagnostic terminé (écart de vitesse aperçu app vs
// matériel réel). Accumule sur ~1s puis imprime un résumé (Serial 115200) :
// "intervalle reel" = temps effectivement écoulé entre 2 pas de défilement
// (à comparer à stepIntervalMs demandé) ; "redraw+blit" = part de cet
// intervalle passée dans fillScreen/blitBitmapWindow/blit (donc SPI inclus)
// — ce qui n'est PAS dans "redraw+blit" mais fait grimper "intervalle reel"
// vient d'ailleurs dans loop() (BLE, autre canal, etc).
#define LOG_SCROLL_TIMING 1
#if LOG_SCROLL_TIMING
struct ScrollTimingStats {
  uint32_t intervalMinMs = UINT32_MAX, intervalMaxMs = 0, intervalSumMs = 0;
  uint32_t redrawMinUs = UINT32_MAX, redrawMaxUs = 0, redrawSumUs = 0;
  uint16_t count = 0;
  uint32_t lastReportMs = 0;

  void record(uint32_t intervalMs, uint32_t redrawUs) {
    if (intervalMs < intervalMinMs) intervalMinMs = intervalMs;
    if (intervalMs > intervalMaxMs) intervalMaxMs = intervalMs;
    intervalSumMs += intervalMs;
    if (redrawUs < redrawMinUs) redrawMinUs = redrawUs;
    if (redrawUs > redrawMaxUs) redrawMaxUs = redrawUs;
    redrawSumUs += redrawUs;
    count++;
  }

  void reportIfDue(const char *label, uint32_t stepIntervalMs) {
    uint32_t now = millis();
    if (count == 0 || now - lastReportMs < 1000) return;
    Serial.printf(
        "[timing] %-10s demande=%lums/px  intervalle reel: min=%lu avg=%lu max=%lu ms  "
        "redraw+blit: min=%lu avg=%lu max=%lu us  (n=%u)\n",
        label, (unsigned long)stepIntervalMs, (unsigned long)intervalMinMs,
        (unsigned long)(intervalSumMs / count), (unsigned long)intervalMaxMs,
        (unsigned long)redrawMinUs, (unsigned long)(redrawSumUs / count),
        (unsigned long)redrawMaxUs, count);
    intervalMinMs = UINT32_MAX;
    intervalMaxMs = 0;
    intervalSumMs = 0;
    redrawMinUs = UINT32_MAX;
    redrawMaxUs = 0;
    redrawSumUs = 0;
    count = 0;
    lastReportMs = now;
  }
};

ScrollTimingStats s_individualTiming;
ScrollTimingStats s_sequentialTiming;
#endif
// --- FIN DEBUG TEMPORAIRE ---

// --- Helpers ---

// Recalibrées en 2 segments (voir specs.md §6.3) : 1..5 reproduit la plage
// complète de l'ancien réglage (l'ancienne vitesse 10 devient la nouvelle
// vitesse 5), puis 5..10 continue d'accélérer au-delà, plus doucement.
// Miroir exact requis côté app dans glasses_timing.dart (scrollStepIntervalMs
// / blinkHalfPeriodMs) — voir la note en tête de ce fichier.
uint32_t stepIntervalFromSpeed(uint8_t speed) {
  uint8_t s = speed < 1 ? 1 : (speed > 10 ? 10 : speed);
  // vitesse 1 -> 60ms/px, vitesse 5 -> 10ms/px, vitesse 10 -> 5ms/px.
  if (s <= 5) return map(s, 1, 5, 60, 10);
  return map(s, 5, 10, 10, 5);
}

// Demi-période (allumé OU éteint) du mode clignotant, voir DIR_BLINK dans
// updateTextChannel(). Plancher volontairement plus prudent que le
// défilement (voir stepIntervalFromSpeed) pour rester dans un rythme de
// clignotement franc plutôt qu'un scintillement gênant/potentiellement
// inconfortable pour un écran porté près des yeux.
uint32_t blinkHalfPeriodFromSpeed(uint8_t speed) {
  uint8_t s = speed < 1 ? 1 : (speed > 10 ? 10 : speed);
  // vitesse 1 -> 600ms, vitesse 5 -> 200ms, vitesse 10 -> 150ms.
  if (s <= 5) return map(s, 1, 5, 600, 200);
  return map(s, 5, 10, 200, 150);
}

void blit(Adafruit_ST7735 &tft, GFXcanvas16 &canvas) {
  tft.drawRGBBitmap(0, 0, canvas.getBuffer(), SCREEN_W, SCREEN_H);
}

// Nearest-neighbor upscale depuis la résolution de travail (srcW x srcH,
// pixels RGB565 big-endian, voir note en tête de fichier) vers SCREEN_W x
// SCREEN_H, directement dans le canvas cible.
void upscaleNearestToCanvas(GFXcanvas16 &canvas, const uint8_t *pixelsBE, uint8_t srcW,
                             uint8_t srcH) {
  if (srcW == 0 || srcH == 0 || pixelsBE == nullptr) return;
  for (uint16_t y = 0; y < SCREEN_H; y++) {
    uint8_t sy = (uint16_t)((uint32_t)y * srcH / SCREEN_H);
    for (uint16_t x = 0; x < SCREEN_W; x++) {
      uint8_t sx = (uint16_t)((uint32_t)x * srcW / SCREEN_W);
      uint32_t si = ((uint32_t)sy * srcW + sx) * 2;
      uint16_t color = ((uint16_t)pixelsBE[si] << 8) | pixelsBE[si + 1];
      canvas.drawPixel(x, y, color);
    }
  }
}

// Copie la fenêtre [0, SCREEN_W) d'un bitmap RGB565 big-endian (largeur
// srcW, hauteur SCREEN_H, voir note en tête de fichier) dans canvas, le
// bitmap étant positionné à l'abscisse horizontale originX (peut être
// négatif ou dépasser SCREEN_W : la partie hors cadre est ignorée). Utilisé
// pour le texte (voir protocol.h : bitmap déjà rendu côté app, le firmware
// ne fait plus que le déplacer/afficher).
void blitBitmapWindow(GFXcanvas16 &canvas, const uint8_t *bitmapBE, uint16_t srcW,
                       int32_t originX) {
  if (bitmapBE == nullptr || srcW == 0) return;
  int32_t xStart = originX < 0 ? 0 : originX;
  int32_t xEnd = originX + (int32_t)srcW;
  if (xEnd > SCREEN_W) xEnd = SCREEN_W;
  if (xStart >= xEnd) return;
  for (uint16_t y = 0; y < SCREEN_H; y++) {
    for (int32_t x = xStart; x < xEnd; x++) {
      uint32_t sx = (uint32_t)(x - originX);
      uint32_t si = ((uint32_t)y * srcW + sx) * 2;
      uint16_t color = ((uint16_t)bitmapBE[si] << 8) | bitmapBE[si + 1];
      canvas.drawPixel(x, y, color);
    }
  }
}

// --- Rendu texte (channel indépendant gauche/droit) ---

void updateTextChannel(ScreenChannel &ch, Adafruit_ST7735 &tft, GFXcanvas16 &canvas) {
  uint32_t now = millis();

  if (ch.direction == EyzoProtocol::DIR_STATIC) {
    if (ch.needsRedraw) {
      // Bitmap statique = déjà plein écran (SCREEN_W x SCREEN_H), fond inclus.
      canvas.fillScreen(ch.colorBg);
      blitBitmapWindow(canvas, ch.textBitmap, ch.textBitmapWidth, 0);
      blit(tft, canvas);
      ch.needsRedraw = false;
    }
    return;
  }

  if (ch.direction == EyzoProtocol::DIR_BLINK) {
    if (ch.needsRedraw) {
      ch.blinkOn = true;
      ch.lastBlinkMs = now;
      ch.needsRedraw = false;
    } else if (now - ch.lastBlinkMs < ch.blinkHalfPeriodMs) {
      return;
    } else {
      ch.lastBlinkMs = now;
      ch.blinkOn = !ch.blinkOn;
    }
    canvas.fillScreen(ch.colorBg);
    if (ch.blinkOn) blitBitmapWindow(canvas, ch.textBitmap, ch.textBitmapWidth, 0);
    blit(tft, canvas);
    return;
  }

  // Défilement (0 = gauche, 1 = droite) — sens "intuitif" pour un écran seul :
  // direction=0 entre par la droite et sort par la gauche, direction=1 l'inverse.
  // Le bitmap ne contient que le texte (largeur ch.textBitmapWidth) : le
  // fond est repeint à chaque frame avant d'y positionner la fenêtre.
  if (ch.needsRedraw) {
    ch.scrollX =
        (ch.direction == EyzoProtocol::DIR_LEFTWARD) ? SCREEN_W : -(int32_t)ch.textBitmapWidth;
    ch.lastTickMs = now;
    ch.needsRedraw = false;
    canvas.fillScreen(ch.colorBg);
    blitBitmapWindow(canvas, ch.textBitmap, ch.textBitmapWidth, ch.scrollX);
    blit(tft, canvas);
    return;
  }
  if (now - ch.lastTickMs >= ch.stepIntervalMs) {
    // Le redraw (fillScreen + blit SPI) peut prendre plus longtemps que
    // stepIntervalMs à vitesse élevée (goulot SPI, voir diagnostic
    // [timing]) : on avance donc de plusieurs pixels d'un coup pour
    // rattraper le temps réellement écoulé, plutôt que de plafonner la
    // vitesse perçue au débit SPI. lastTickMs avance de steps*stepIntervalMs
    // (pas = now) pour ne pas accumuler de retard de phase d'un tick à
    // l'autre.
    uint32_t elapsedMs = now - ch.lastTickMs;
    int32_t steps = elapsedMs / ch.stepIntervalMs;
    if (steps < 1) steps = 1;
    ch.lastTickMs += steps * ch.stepIntervalMs;
    if (ch.direction == EyzoProtocol::DIR_LEFTWARD) {
      ch.scrollX -= steps;
      if (ch.scrollX < -(int32_t)ch.textBitmapWidth) ch.scrollX = SCREEN_W;
    } else {
      ch.scrollX += steps;
      if (ch.scrollX > SCREEN_W) ch.scrollX = -(int32_t)ch.textBitmapWidth;
    }
#if LOG_SCROLL_TIMING
    uint32_t redrawStartUs = micros();
#endif
    canvas.fillScreen(ch.colorBg);
    blitBitmapWindow(canvas, ch.textBitmap, ch.textBitmapWidth, ch.scrollX);
    blit(tft, canvas);
#if LOG_SCROLL_TIMING
    s_individualTiming.record(elapsedMs, micros() - redrawStartUs);
    s_individualTiming.reportIfDue("individuel", ch.stepIntervalMs);
#endif
  }
}
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
void loop() {
  if (s_seq.active) {
    updateSequential();
  } else {
    updateChannel(s_left, tftLeft, canvasLeft);
    updateChannel(s_right, tftRight, canvasRight);
  }
  updatePairingAnimation();
}

void showBoot() {
  s_left.mode = Mode::None;
  s_right.mode = Mode::None;
  s_seq.active = false;
  s_statusScreen = StatusScreen::None;

  clearBothCanvases();
  int32_t x = (SCREEN_W - PANDA_BOOT_ICON_W) / 2;
  int32_t y = (SCREEN_H - PANDA_BOOT_ICON_H) / 2;
  canvasLeft.drawRGBBitmap(x, y, kPandaBootIconRgb565, PANDA_BOOT_ICON_W, PANDA_BOOT_ICON_H);
  canvasRight.drawRGBBitmap(x, y, kPandaBootIconRgb565, PANDA_BOOT_ICON_W, PANDA_BOOT_ICON_H);
  blitBoth();
}

void showDisconnected() { drawBluetoothStatus(ST77XX_RED, /*checkNotCross=*/false); }
void showConnected() { drawBluetoothStatus(ST77XX_GREEN, /*checkNotCross=*/true); }

void showPairing(uint32_t secondsLeft) {
  s_left.mode = Mode::None;
  s_right.mode = Mode::None;
  s_seq.active = false;

  s_pairingStartMs = millis();
  s_pairingDurationMs = secondsLeft * 1000UL;
  s_lastPairingFrameMs = 0;  // force un premier rendu immédiat, voir updatePairingAnimation()
  s_statusScreen = StatusScreen::Pairing;
  updatePairingAnimation();
}

// Éteint un canal (mode/animation/image/texte réinitialisés, canvas noir
// blitté) — utilisé par clearScreen() et par setAnimation() pour l'écran non
// ciblé par une nouvelle animation (voir setAnimation()).
void blankChannel(ScreenChannel &ch, Adafruit_ST7735 &tft, GFXcanvas16 &canvas) {
  ch.mode = Mode::None;
  ch.anim.reset();
  ch.freeStatic();
  ch.freeTextBitmap();
  canvas.fillScreen(ST77XX_BLACK);
  blit(tft, canvas);
}

void clearScreen(uint8_t screenByte) {
  if (screenByte == EyzoProtocol::SCREEN_SEQUENTIAL) {
    s_seq.active = false;
    s_seq.freeTextBitmap();
  }

  if (screenByte == EyzoProtocol::SCREEN_LEFT || screenByte == EyzoProtocol::SCREEN_SIMULTANEOUS ||
      screenByte == EyzoProtocol::SCREEN_SEQUENTIAL) {
    blankChannel(s_left, tftLeft, canvasLeft);
  }
  if (screenByte == EyzoProtocol::SCREEN_RIGHT || screenByte == EyzoProtocol::SCREEN_SIMULTANEOUS ||
      screenByte == EyzoProtocol::SCREEN_SEQUENTIAL) {
    blankChannel(s_right, tftRight, canvasRight);
  }
}

void setText(uint8_t screenByte, uint8_t direction, uint8_t speed, uint16_t colorBg,
             uint16_t bitmapWidth, uint16_t gapNativePx, const uint8_t *pixelsRgb565,
             uint32_t pixelLen) {
  uint32_t stepMs = stepIntervalFromSpeed(speed);
  uint32_t blinkMs = blinkHalfPeriodFromSpeed(speed);

  if (screenByte == EyzoProtocol::SCREEN_SEQUENTIAL) {
    if (direction == EyzoProtocol::DIR_STATIC || direction == EyzoProtocol::DIR_BLINK) {
      // specs.md §6.3 : sans effet particulier en statique/clignotant,
      // équivalent à Simultané dans ce cas (gapNativePx n'a pas de sens hors
      // Séquentiel, ignoré par la branche ci-dessous).
      setText(EyzoProtocol::SCREEN_SIMULTANEOUS, direction, speed, colorBg, bitmapWidth,
              gapNativePx, pixelsRgb565, pixelLen);
      return;
    }
    s_left.mode = Mode::None;
    s_left.anim.reset();
    s_left.freeStatic();
    s_left.freeTextBitmap();
    s_right.mode = Mode::None;
    s_right.anim.reset();
    s_right.freeStatic();
    s_right.freeTextBitmap();

    s_seq.freeTextBitmap();
    s_seq.textBitmap = (uint8_t *)heap_caps_malloc(pixelLen, MALLOC_CAP_SPIRAM);
    if (!s_seq.textBitmap) s_seq.textBitmap = (uint8_t *)malloc(pixelLen);  // repli SRAM
    if (!s_seq.textBitmap) {
      Serial.println("[Display] echec allocation bitmap texte (sequentiel)");
      s_seq.active = false;
      return;
    }
    memcpy(s_seq.textBitmap, pixelsRgb565, pixelLen);
    s_seq.active = true;
    s_seq.textBitmapWidth = bitmapWidth;
    s_seq.colorBg = colorBg;
    s_seq.direction = direction;
    s_seq.stepIntervalMs = stepMs;
    s_seq.gapNativePx = gapNativePx;
    s_seq.needsRedraw = true;
    return;
  }

  s_seq.active = false;
  s_seq.freeTextBitmap();
  if (screenByte == EyzoProtocol::SCREEN_LEFT || screenByte == EyzoProtocol::SCREEN_SIMULTANEOUS) {
    applyTextBitmapToChannel(s_left, direction, colorBg, stepMs, blinkMs, bitmapWidth,
                              pixelsRgb565, pixelLen);
  }
  if (screenByte == EyzoProtocol::SCREEN_RIGHT || screenByte == EyzoProtocol::SCREEN_SIMULTANEOUS) {
    applyTextBitmapToChannel(s_right, direction, colorBg, stepMs, blinkMs, bitmapWidth,
                              pixelsRgb565, pixelLen);
  }
}

void setStaticImage(uint8_t screenByte, uint8_t width, uint8_t height,
                     const uint8_t *pixelsRgb565, uint16_t pixelLen) {
  s_seq.active = false;
  s_seq.freeTextBitmap();
  // Non exposé côté app pour cette commande (specs.md §6.3) : traité comme
  // Simultané par sécurité plutôt que de laisser un comportement non défini.
  if (screenByte == EyzoProtocol::SCREEN_SEQUENTIAL) screenByte = EyzoProtocol::SCREEN_SIMULTANEOUS;

  if (screenByte == EyzoProtocol::SCREEN_LEFT || screenByte == EyzoProtocol::SCREEN_SIMULTANEOUS)
    applyStaticImageToChannel(s_left, width, height, pixelsRgb565, pixelLen);
  if (screenByte == EyzoProtocol::SCREEN_RIGHT || screenByte == EyzoProtocol::SCREEN_SIMULTANEOUS)
    applyStaticImageToChannel(s_right, width, height, pixelsRgb565, pixelLen);
}

void setAnimation(uint8_t screenByte, uint8_t width, uint8_t height, uint8_t frameCount,
                   uint16_t frameDelayMs, const uint8_t *pixelsRgb565, uint32_t pixelLen) {
  s_seq.active = false;
  s_seq.freeTextBitmap();
  // Non exposé côté app pour cette commande (specs.md §6.3) : traité comme
  // Simultané par sécurité plutôt que de laisser un comportement non défini.
  if (screenByte == EyzoProtocol::SCREEN_SEQUENTIAL) screenByte = EyzoProtocol::SCREEN_SIMULTANEOUS;

  // L'écran non ciblé par cette animation est explicitement éteint : sans
  // ça, une animation reçue précédemment sur cet écran (ex: envoyée en
  // Simultané, puis remplacée par une nouvelle animation ciblant un seul
  // écran) continuerait de tourner dessus indéfiniment.
  if (screenByte == EyzoProtocol::SCREEN_LEFT) blankChannel(s_right, tftRight, canvasRight);
  if (screenByte == EyzoProtocol::SCREEN_RIGHT) blankChannel(s_left, tftLeft, canvasLeft);

  if (screenByte == EyzoProtocol::SCREEN_LEFT || screenByte == EyzoProtocol::SCREEN_SIMULTANEOUS)
    applyAnimationToChannel(s_left, width, height, frameCount, frameDelayMs, pixelsRgb565,
                             pixelLen);
  if (screenByte == EyzoProtocol::SCREEN_RIGHT || screenByte == EyzoProtocol::SCREEN_SIMULTANEOUS)
    applyAnimationToChannel(s_right, width, height, frameCount, frameDelayMs, pixelsRgb565,
                             pixelLen);
}

}  // namespace DisplayManager

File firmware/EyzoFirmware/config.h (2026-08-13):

#pragma once

// Brochage Seeed XIAO ESP32S3 — voir firmware/README.md pour le schéma complet.
// Bus SPI partagé (SCK/MOSI) entre les 2 écrans, CS et RST séparés par écran
// (le RST ne peut PAS être partagé : le reset matériel réinitialiserait aussi
// l'écran déjà configuré, voir la note dans display_manager.cpp).
#define PIN_TFT_SCK 7        // D8
#define PIN_TFT_MOSI 9       // D10
#define PIN_TFT_CS_LEFT 1    // D0
#define PIN_TFT_CS_RIGHT 2   // D1
#define PIN_TFT_DC 3         // D2 (partagé)
#define PIN_TFT_RST_LEFT 4   // D3
#define PIN_TFT_RST_RIGHT 5  // D4
#define PIN_BUTTON 6         // D5

// Résolution native du panneau ST7735S monté en paysage (voir specs.md §2).
#define SCREEN_W 160
#define SCREEN_H 128

// Bouton poussoir : appui long = mode appairage (voir specs.md §4.1).
#define BUTTON_DEBOUNCE_MS 30
#define BUTTON_LONG_PRESS_MS 800

// Fenêtre pendant laquelle un nouvel appareil (jamais connecté / oublié)
// peut s'appairer après un appui long. Passé ce délai, retour au mode
// "connexion automatique au dernier appareil connu uniquement".
#define PAIRING_WINDOW_MS 60000UL

// Nombre max de frames stockées pour une animation (mémoire allouée en PSRAM,
// voir README — "PSRAM: OPI PSRAM" à activer dans le menu Outils).
#define MAX_ANIMATION_FRAMES 64

// Taille max d'un payload réassemblé (avant compression), voir
// ble_manager.cpp — deux buffers de cette taille sont alloués en PSRAM
// (réassemblage + décompression, voir begin()), pas de quoi tenir dans la
// SRAM interne. Doit couvrir le plus gros cas d'usage app : une animation
// complète (SET_ANIMATION, voir protocol.h) envoyée en un seul bloc,
// frame_count x width x height x 2 octets — jusqu'à ~1,2 Mo pour la
// résolution de travail native (160x128) au nombre de frames par défaut de
// l'app (30, voir image_conversion.dart), avec de la marge. Une image
// plein écran (~41 Ko) ou un bitmap de texte défilant tiennent très
// largement dedans. 2 x cette taille (~3 Mo) laisse une marge confortable
// sur les 8 Mo de PSRAM du XIAO ESP32S3 pour le reste (animations déjà
// affichées sur les 2 écrans, canevas, pile BLE).
#define MAX_PAYLOAD_SIZE 1500000UL

// La lib zlib_turbo (voir ble_manager.cpp) fait des lectures/écritures non
// alignées par mots de 32 bits pour accélérer la décompression : ses buffers
// d'entrée ET de sortie doivent être alloués quelques octets plus grands que
// la taille utile réelle pour rester dans les clous côté allocation mémoire
// (voir bitbank2/zlib_turbo README, "input buffer and output buffer need to
// be allocated 4-8 bytes larger than needed"). Appliqué au buffer de
// réassemblage (entrée, potentiellement compressée) et au buffer de
// décompression (sortie), tous deux alloués en PSRAM, voir begin() dans
// ble_manager.cpp.
#define ZLIB_TURBO_BUFFER_PADDING 16UL

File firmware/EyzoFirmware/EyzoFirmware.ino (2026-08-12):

// Firmware ESP32-S3 pour les lunettes connectées Eyzo.
// Voir firmware/README.md pour l'installation Arduino IDE et le schéma de
// brochage, et specs.md (racine du projet) pour le contrat applicatif
// complet (app Flutter <-> firmware).
//
// Comportement "enceinte Bluetooth" (specs.md §4.1) :
//   - 1ère mise en route (aucun appareil mémorisé) -> accepte et mémorise le
//     premier téléphone qui se connecte.
//   - Appareil déjà mémorisé -> reconnexion automatique au démarrage et à
//     toute coupure.
//   - Appui LONG sur le bouton -> ouvre une fenêtre de 60s pendant laquelle
//     un nouvel appareil peut s'appairer.

#include "ble_manager.h"
#include "button_manager.h"
#include "config.h"
#include "display_manager.h"
#include "protocol.h"

void handleLongPress() {
  Serial.println("[BOUTON] Appui long détecté");
  Serial.println("[BLE] Passage en mode appairage");

  BleManager::enterPairingMode();
}

void setup() {
  Serial.begin(115200);

  // Attend au maximum 5 secondes que le port série USB soit ouvert.
  unsigned long serialStart = millis();

  while (!Serial && millis() - serialStart < 5000) {
    delay(10);
  }

  delay(500);

  Serial.println();
  Serial.println("================================");
  Serial.println("       DEMARRAGE EYZO");
  Serial.println("================================");

  Serial.println("[DISPLAY] Initialisation...");
  DisplayManager::begin();
  Serial.println("[DISPLAY] Initialisation terminée");

  Serial.println("[DISPLAY] Affichage de l'écran de démarrage...");
  DisplayManager::showBoot();
  Serial.println("[DISPLAY] Écran de démarrage affiché");

  Serial.println("[BOUTON] Initialisation...");
  ButtonManager::begin();
  ButtonManager::onLongPress(handleLongPress);
  Serial.println("[BOUTON] Initialisation terminée");

  Serial.println("[BLE] Initialisation...");
  BleManager::begin();
  Serial.println("[BLE] Initialisation terminée");

  Serial.println("================================");
  Serial.println("        EYZO EST PRÊT");
  Serial.println("================================");
}

void loop() {
  ButtonManager::loop();
  BleManager::loop();
  DisplayManager::loop();

  // Message toutes les secondes pour vérifier que le programme
  // fonctionne toujours et ne s'est pas bloqué.
  static unsigned long lastSerialMessage = 0;

  if (millis() - lastSerialMessage >= 1000) {
    lastSerialMessage = millis();
    Serial.println("[SYSTEME] Firmware en fonctionnement");
  }
}

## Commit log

2026-07-19 Initialise le scaffold Flutter Eyzo (app de contrôle des lunettes ESP32)
    Structure complète selon specs.md : thème dark N&B, protocole BLE binaire
    chunké (texte/image/animation), service de connexion/reconnexion auto,
    4 modes de contenu (texte défilant, animations prédéfinies, import
    image/GIF, éditeur pixel-art), favoris persistés en local (Hive).
2026-07-19 Aperçu miroir double-verre, retrait des animations presets, banque GIF clavier
    - Aperçu des 2 verres côte à côte (convention miroir) sur Texte/Import/Éditeur,
    avec état "éteint" pour l'écran non ciblé, et SafeArea pour ne plus masquer
    les boutons d'envoi sous la nav système Android.
    - Suppression de la bibliothèque d'animations prédéfinies (redondante avec
    l'import de GIF), nom de l'app corrigé en "Eyzo" (majuscule) dans le manifest.
    - Import GIF : insertion directe depuis la banque du clavier (commitContent
    Android via contentInsertionConfiguration + pont natif Kotlin pour les URI
    content://), en remplacement de Tenor (API fermée aux nouveaux clients).
    - Écran Imp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
2026-07-19 Mode séquentiel, dessin au doigt et corrections d'aperçu
    - Renomme "Les deux" en "Simultané" et ajoute le mode "Séquentiel"
    (texte uniquement) : les 2 écrans forment une bande de défilement
    continue, l'écran de départ dépendant de la direction.
    - Corrige la troncature du texte à ~11 caractères dans les aperçus
    (Align contraignait le rendu à la largeur du cadre visible) via un
    OverflowBox + mesure réelle de la largeur du texte ; corrige au passage
    le calcul de la distance de défilement pour les messages longs.
    - Éditeur pixel-art : dessin au doigt en continu (Listener au lieu de
    GestureDetector, scroll de la page désactivé pendant le tracé),
    bouton "Annuler" (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
2026-07-19 Corrige centrage, vitesse d'animation, écran départ séquentiel et ratio d'aperçu
    - Champ Message : retire le floating label animé (glitch au clic), garde
    un label statique + hint fixe "Votre texte...".
    - Corrige l'écran de départ en mode Séquentiel : la jointure entre les 2
    fenêtres ne correspondait pas au connecteur visuel entre les verres,
    inversant l'écran de départ perçu.
    - Corrige le centrage vertical du texte dans les aperçus (OverflowBox ne
    desserrait que la largeur, pas la hauteur, ce qui collait le texte en
    haut du cadre).
    - Corrige la vitesse de défilement des aperçus, sans effet jusqu'ici car
    AnimationController.repeat() fige la durée dès son premier a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
2026-07-19 Thème panda kawaii, favoris visuels, aperçus cohérents et fix permissions BLE Android 12+
    - Nouveau thème (police Quicksand, accent rose, boutons arrondis) et icône
    favori qui reflète l'état sauvegardé sur éditeur/texte/import
    - Aperçu de l'éditeur pixel-art aligné sur les autres pages : même largeur
    de verre et même placeholder "vide" (au lieu d'un rectangle noir qui se
    fondait dans le fond de l'app)
    - Cartes de la page d'accueil étirées pour occuper tout l'espace vertical
    - Fix scan Bluetooth : ACCESS_FINE_LOCATION est exclue par le système sur
    Android 12+ (maxSdkVersion=30 dans le manifest), donc l'exiger sur ces
    versions bloquait le scan en permanence malgré l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
2026-08-01 Adapte l'app aux nouveaux écrans 1,77" 128x160 (montés en paysage, 160x128 effectif)
    Ajoute GlassesDisplay comme point d'entrée unique pour la résolution native
    et les grilles de travail, corrige l'import image/GIF pour ne plus déformer
    (modes Remplir/Image entière) et l'aperçu lunettes pour respecter le vrai
    ratio de la grille.
2026-08-01 Ajoute la police Pixel, le clignotement à vitesse fixe et la résolution native par défaut
    - Police "Pixel" (Press Start 2P) avec rendu majuscule forcé, envoyée telle
    qu'affichée aux lunettes
    - Mode "Clignotant" avec une durée de cycle indépendante de la longueur du
    texte (au lieu d'hériter de la logique de défilement)
    - Vitesse et taille de texte étendues sur une échelle 1-10
    - Mode séquentiel par défaut à l'ouverture de l'écran Texte
    - Résolution de travail par défaut de l'import image/GIF passée en 160x128
    (plein écran natif) plutôt que 40x32
2026-08-01 Ajoute le réglage de l'espace inter-écran pour le mode séquentiel
    Les 2 écrans ne sont pas collés (28x35mm chacun en paysage). Rajoute une
    double flèche cliquable entre les 2 verres dans l'aperçu (DualLensRow),
    qui ouvre une modale de réglage en mm (virgule ou point pour les
    dixièmes), persistée via Hive. En mode Séquentiel, ce délai est converti
    en distance de traversée invisible entre les 2 écrans à la vitesse de
    défilement courante, pour un aperçu fidèle à l'espace physique réel.
2026-08-12 Ajoute le firmware ESP32 et bascule le rendu texte/image en bitmap côté app, avec compression zlib et un protocole BLE fiabilisé (ACK/NACK, un seul transfert à la fois, priorité de connexion et taill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
2026-08-13 Envoie les animations en un seul bloc compressé (SET_ANIMATION) au lieu d'une commande par frame
    Regrouper toutes les frames avant compression laisse zlib exploiter leur ressemblance (fond fixe, petite partie qui bouge sur un GIF typique) et réduit le nombre d'allers-retours BLE. Effet de bord : l'animation en cours n'est plus modifiée avant que la nouvelle soit reçue en entier, donc plus de gel pendant le transfert.
    [config.h, display_manager.cpp]
2026-08-13 Affiche le bitmap réellement envoyé dans les aperçus texte, corrige le sens de défilement en mode Séquentiel et clarifie la convention L/R (porteur) vs gauche/droite (aperçu miroir)
    Les aperçus (défilement individuel et séquentiel) rendent désormais le
    bitmap exact envoyé aux lunettes, animé aux mêmes cadences que le
    firmware (voir glasses_timing.dart), au lieu d'un second rendu Flutter
    approximatif. Le mode Séquentiel ignorait la vue miroir de l'app lors
    du calcul de position, ce qui inversait le sens de glissement à
    l'intérieur de chaque écran (corrigé côté app et firmware, qui doit
    rester un miroir exact). Les légendes de l'aperçu passent de
    "Gauche"/"Droite" à "L"/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
    [config.h, display_manager.cpp]
2026-08-13 Corrige la vitesse de défilement réelle (rattrapage de pixels si le blit SPI dépasse le délai demandé) et efface l'écran non ciblé par une nouvelle animation
    Le défilement (texte individuel et séquentiel) avançait toujours d'1 px
    par tick, plafonnant la vitesse perçue au temps de blit SPI (~20 ms/écran
    au défaut 16 MHz, mesuré via un log temporaire) au lieu de la vitesse
    demandée — flagrant en Séquentiel où 2 écrans sont blittés par tick. On
    avance maintenant de plusieurs pixels d'un coup pour rattraper le temps
    réellement écoulé.
    setAnimation() éteint aussi désormais l'écran non ciblé par une nouvelle
    animation à écran unique, pour ne pas laisser une animation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
    [display_manager.cpp]
2026-08-13 Compense la rotation physique de 180° de l'écran Droit (nappes montées vers l'intérieur de la monture)
    Les 2 écrans sont montés tête-bêche l'un par rapport à l'autre (nappes
    vers l'intérieur) : rotation 3 sur tftRight au lieu de 1 compense ça au
    niveau du contrôleur (MADCTL), sans changement côté bitmap/canvas.
2026-08-13 Transmet l'écart inter-écran au firmware en mode Séquentiel (au lieu d'une simulation purement visuelle côté app)
    L'écart réglé par l'utilisateur (interLensGapProvider) était pris en
    compte dans l'aperçu mais jamais envoyé aux lunettes : le firmware
    traitait toujours les 2 écrans comme une bande continue de 2*SCREEN_W
    pile, sans pause en traversant l'écart physique entre les 2 écrans.
    Ajoute un champ gap_native_px (uint16 LE) au payload SET_TEXT, utilisé
    côté firmware pour élargir la bande virtuelle de défilement séquentiel
    (2*SCREEN_W + gap_native_px) exactement comme le fait déjà l'aperçu.
    GlassesDisplay.gapMmToNativePx() factorise la conversion mm -> px
    natifs pour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
    [display_manager.cpp]
2026-08-14 Ajoute le plan de référence PCB (contour lunettes, écrans, ESP32-S3 Mini, bouton BT, interrupteur, alim batterie)
    Repère vectoriel dimensionné en mm servant de base au futur routage PCB
    dans firmware/EyzoFirmware/ : contour extrait du logo, cadres d'écran,
    et placement mécanique des composants verso.
2026-08-16 Ajoute l'icône panda vectorisée (SVG propre, sans bruit de tramage) et le schéma Glasses.svg
    Corrige le pipeline potrace (dithering désactivé + seuillage net + despeckle) qui produisait un tracé bruité sur les zones grises.
    [Eyzo.kicad_pcb]
2026-08-17 Remplace les écrans d'état texte par des icônes (boot panda, statut BLE, appairage animé)
    Écran de démarrage : logo panda (assets/icon/panda_icon.png rebaké en bitmap
    112x112) au lieu du texte "EYZO". Connecté/déconnecté : logo Bluetooth
    officiel (rebaké depuis bluetooth.jpg, même boîte englobante que le panda)
    avec une pastille check/croix fusionnée sur son coin bas-droit. Appairage :
    même logo, animé (pulse + barre de compte à rebours qui se vide) via
    DisplayManager::loop() au lieu d'un unique message statique.
